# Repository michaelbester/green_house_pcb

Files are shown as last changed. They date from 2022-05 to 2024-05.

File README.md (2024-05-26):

This is the PCB design for the green house controller.  I used Kicad 6 to design the schematic and layout the board.

green_house_controller

pcb_pic

The uC pins connected to the fan #2, misc, and vent relays where incorrect.  
I jumpered these pins to unused pins that had output capability, but I can't get the outputs to go high.

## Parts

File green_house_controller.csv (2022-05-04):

Source: | /Volumes/MASTERs 17/green_house_controller/green_house_controller.kicad_sch
Date: | Friday, April 29, 2022 at 02:57:39 PM
Tool: | Eeschema (6.0.4-0)
Generator: | /Applications/KiCad/KiCad.app/Contents/SharedSupport/plugins/bom_csv_grouped_by_value_with_fp.py
Component Count: | 110
Ref | Qnty | Value | Cmp name | Footprint | Description | Vendor
C1, C10, | 2 | 0.1uF | C | Capacitor_SMD:C_0805_2012Metric | Unpolarized capacitor
C2, | 1 | 20uF | C | Capacitor_SMD:C_0805_2012Metric | Unpolarized capacitor
C3, | 1 | 1uF | C | Capacitor_SMD:C_0805_2012Metric | Unpolarized capacitor
C4, C5, C15, | 3 | 4.7uF | C | Capacitor_SMD:C_0805_2012Metric | Unpolarized capacitor
C6, | 1 | 0.01uF | C | Capacitor_SMD:C_0805_2012Metric | Unpolarized capacitor
C7, | 1 | 47pF | C | Capacitor_SMD:C_0805_2012Metric | Unpolarized capacitor
C8, | 1 | 1nF | C | Capacitor_SMD:C_0805_2012Metric | Unpolarized capacitor
C9, | 1 | 15nF | C | Capacitor_SMD:C_0805_2012Metric | Unpolarized capacitor
C11, C12, | 2 | 47uF | C | Capacitor_SMD:C_0805_2012Metric | Unpolarized capacitor
C13, | 1 | 2.2uF | C | Capacitor_SMD:C_0805_2012Metric | Unpolarized capacitor
C14, | 1 | 220pF | C | Capacitor_SMD:C_0805_2012Metric | Unpolarized capacitor
C17, | 1 | 2200uF | C_Polarized_US | Capacitor_THT:CP_Radial_D16.0mm_P7.50mm | Polarized capacitor, US symbol
D1, | 1 | SOL_1 | LED | LED_SMD:LED_0805_2012Metric | Light emitting diode
D2, | 1 | SOL_2 | LED | LED_SMD:LED_0805_2012Metric | Light emitting diode
D3, | 1 | SOL_3 | LED | LED_SMD:LED_0805_2012Metric | Light emitting diode
D4, D9, | 2 | B240 | B240 | Diode_SMD:D_SMB | 40V 2A Schottky Barrier Rectifier Diode, SMB
D5, | 1 | FAN | LED | LED_SMD:LED_0805_2012Metric | Light emitting diode
D6, | 1 | VENT | LED | LED_SMD:LED_0805_2012Metric | Light emitting diode
D7, | 1 | STATUS | LED | LED_SMD:LED_0805_2012Metric | Light emitting diode
D8, | 1 | MISC_1 | LED | LED_SMD:LED_0805_2012Metric | Light emitting diode
D10, | 1 | VENT_1 | LED | LED_SMD:LED_0805_2012Metric | Light emitting diode
D11, D12, D13, D14, D15, D16, | 6 | BAT54S | BAT54S | Package_TO_SOT_SMD:SOT-23 | schottky barrier diode
D17, | 1 | B140-E3 | B140-E3 | Diode_SMD:D_SMA | 40V 1A Schottky Barrier Rectifier Diode, SMA(DO-214AC)
H1, H2, H3, H4, | 4 | MountingHole | MountingHole | MountingHole:MountingHole_3.2mm_M3 | Mounting Hole without connection
J1, | 1 | TC2030-IDC | TC2030-IDC-TC2030-IDC | connector:TC2030-IDC
J2, | 1 | Screw_Terminal_01x10 | Screw_Terminal_01x10 | Connector_Phoenix_MC_HighVoltage:PhoenixContact_MCV_1,5_10-G-5.08_1x10_P5.08mm_Vertical | Generic screw terminal, single row, 01x10, script generated (kicad-library-utils/schlib/autogen/connector/)
J3, | 1 | USB_B_Mini | USB_B_Mini-Connector | Connector_USB:USB_Mini-B_Lumberg_2486_01_Horizontal
J4, | 1 | Screw_Terminal_01x06 | Screw_Terminal_01x06 | Connector_Phoenix_MC_HighVoltage:PhoenixContact_MCV_1,5_6-G-5.08_1x06_P5.08mm_Vertical | Generic screw terminal, single row, 01x06, script generated (kicad-library-utils/schlib/autogen/connector/)
J5, | 1 | Screw_Terminal_01x03 | Screw_Terminal_01x03 | Connector_Phoenix_MC_HighVoltage:PhoenixContact_MCV_1,5_3-G-5.08_1x03_P5.08mm_Vertical | Generic screw terminal, single row, 01x03, script generated (kicad-library-utils/schlib/autogen/connector/)
J6, | 1 | Barrel_Jack | Barrel_Jack | Connector_BarrelJack:BarrelJack_CUI_PJ-102AH_Horizontal | DC Barrel Jack
L1, L2, | 2 | 10uH | INDUCTOR | Inductor_SMD:L_Taiyo-Yuden_NR-50xx | Inductor symbol for simulation only
Q1, Q2, Q7, Q8, Q13, Q19, | 6 | 2N7002 | 2N7002 | Package_TO_SOT_SMD:SOT-23 | 0.115A Id, 60V Vds, N-Channel MOSFET, SOT-23
Q3, Q5, Q9, Q11, Q14, Q16, | 6 | DMP3068L | AO3401A | Package_TO_SOT_SMD:SOT-23 | -4.0A Id, -30V Vds, P-Channel MOSFET, SOT-23
Q4, Q6, Q10, Q12, Q15, Q17, | 6 | DMG3406L | DMG3406L | Package_TO_SOT_SMD:SOT-23 | 3.6A Id, 30V Vds, N-Channel MOSFET, SOT-23
R1, R12, R16, R17, R18, R19, | 6 | 10K | R_US | Resistor_SMD:R_0805_2012Metric | Resistor, US symbol
R2, R3, R4, R6, R7, R8, R9, R10, | 8 | 330 | R_US | Resistor_SMD:R_0805_2012Metric | Resistor, US symbol
R5, R24, R25, R26, R27, R28, R29, R30, R32, R33, R34, R35, R36, | 13 | 1K | R_US | Resistor_SMD:R_0805_2012Metric | Resistor, US symbol
R11, | 1 | 22K | R_US | Resistor_SMD:R_0805_2012Metric | Resistor, US symbol
R13, | 1 | 29.4K | R_US | Resistor_SMD:R_0805_2012Metric | Resistor, US symbol
R14, | 1 | 10.2K | R_US | Resistor_SMD:R_0805_2012Metric | Resistor, US symbol
R15, | 1 | 3.24K | R_US | Resistor_SMD:R_0805_2012Metric | Resistor, US symbol
R20, R21, R22, R23, | 4 | 200 | R_US | Resistor_SMD:R_0805_2012Metric | Resistor, US symbol
R31, | 1 | 51K | R_US | Resistor_SMD:R_0805_2012Metric | Resistor, US symbol
R37, | 1 | 18.7K | R_US | Resistor_SMD:R_0805_2012Metric | Resistor, US symbol
R38, | 1 | 100 | R_US | Resistor_SMD:R_2512_6332Metric | Resistor, US symbol
SW1, | 1 | SW_Push | SW_Push | Button_Switch_SMD:SW_SPST_B3S-1000 | Push button switch, generic, two pins
U1, | 1 | ESP32-WROVER | ESP32-WROVER-esp32-wrover | esp32-wrover:ESP32-WROVER
U2, | 1 | TPS54231 | TPS54233 | Package_SO:SOIC-8_3.9x4.9mm_P1.27mm | 2A, Step Down DC-DC Converter with Eco-mode, 3.5-28V Input Voltage, SO-8
U3, U4, U5, U6, | 4 | TLP3825TP1_F | TLP3825TP1_F | Package_DIP:DIP-8_W7.62mm
U7, | 1 | LM2733XMF | LM2733XMF | Package_TO_SOT_SMD:SOT-23-5 | LM27313, 1A, 40Vout Boost Voltage Regulator, 1.6MHz Frequency, SOT-23-5
U8, | 1 | DHT11 | DHT11 | Sensor:Aosong_DHT11_5.5x12.0_P2.54mm | Temperature and humidity module

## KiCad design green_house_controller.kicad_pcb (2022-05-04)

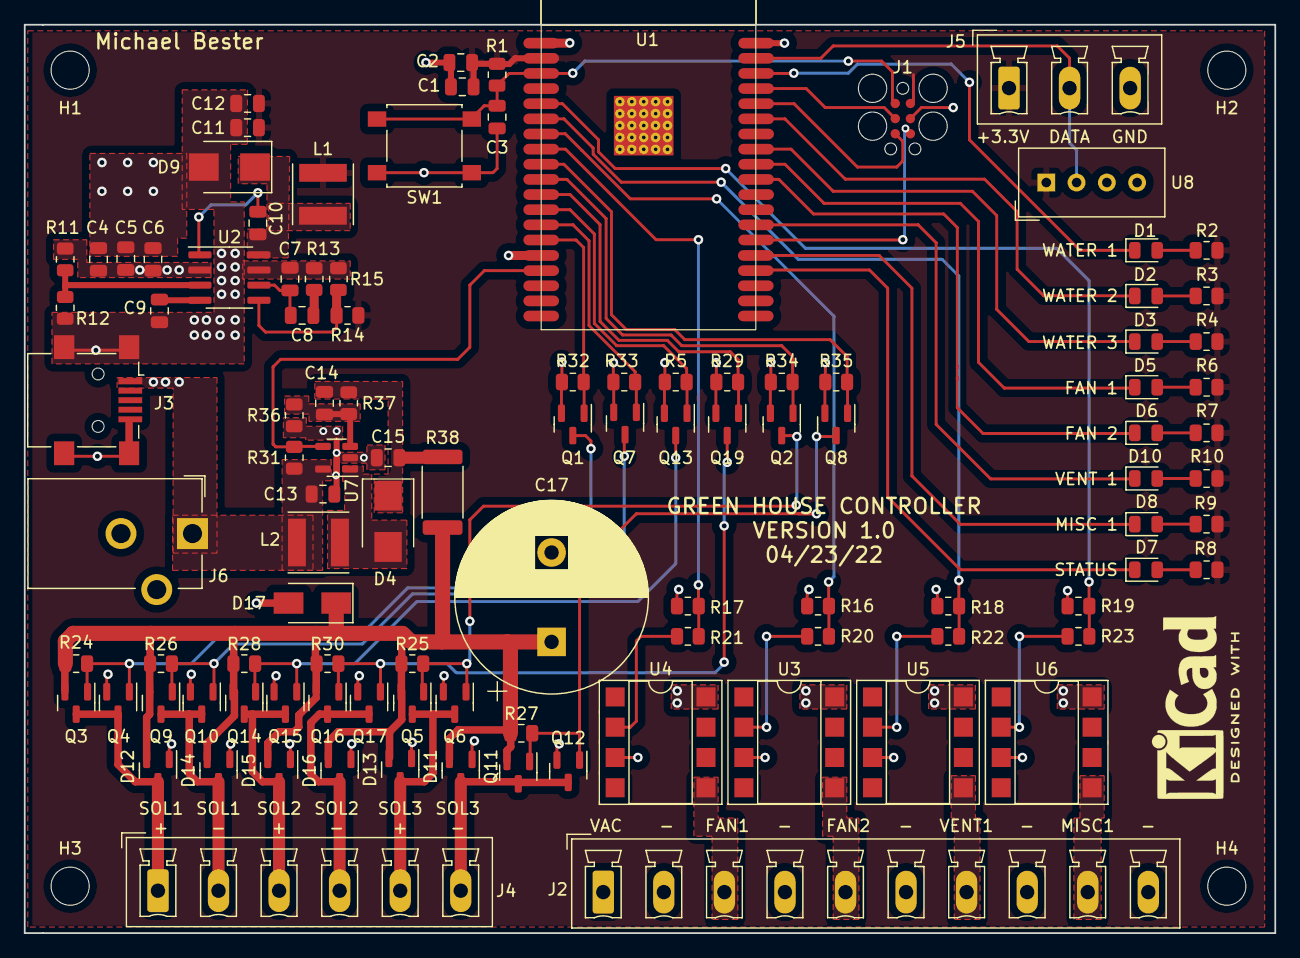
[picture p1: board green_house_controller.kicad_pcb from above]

Board: 2 copper layers, 104.9 x 76.2 mm, 110 parts (0 on the bottom side), 68 nets.

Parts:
C1, C10: 0.1uF; C_0805_2012Metric
C2: 10uF; C_0805_2012Metric
C3: 1uF; C_0805_2012Metric
C4, C5, C15: 4.7uF; C_0805_2012Metric
C6: 0.01uF; C_0805_2012Metric
C7: 47pF; C_0805_2012Metric
C8: 1nF; C_0805_2012Metric
C9: 15nF; C_0805_2012Metric
C11, C12: 47uF; C_0805_2012Metric
C13: 2.2uF; C_0805_2012Metric
C14: 220pF; C_0805_2012Metric
C17: 2200uF; CP_Radial_D16.0mm_P7.50mm
D1: SOL_1; LED_0805_2012Metric
D2: SOL_2; LED_0805_2012Metric
D3: SOL_3; LED_0805_2012Metric
D4, D9: B240; D_SMB
D5: FAN; LED_0805_2012Metric
D6: VENT; LED_0805_2012Metric
D7: STATUS; LED_0805_2012Metric
D8: MISC_1; LED_0805_2012Metric
D10: VENT_1; LED_0805_2012Metric
D11, D12, D13, D14, D15, D16: BAT54S; SOT-23
D17: B140-E3; D_SMA
H1, H2, H3, H4: MountingHole; MountingHole_3.2mm_M3
J1: TC2030-IDC
J2: Screw_Terminal_01x10; PhoenixContact_MCV_1,5_10-G-5.08_1x10_P5.08mm_Vertical
J3: USB_B_Mini; USB_Mini-B_Lumberg_2486_01_Horizontal
J4: Screw_Terminal_01x06; PhoenixContact_MCV_1,5_6-G-5.08_1x06_P5.08mm_Vertical
J5: Screw_Terminal_01x03; PhoenixContact_MCV_1,5_3-G-5.08_1x03_P5.08mm_Vertical
J6: Barrel_Jack; BarrelJack_CUI_PJ-102AH_Horizontal
L1, L2: 10uH; L_Taiyo-Yuden_NR-50xx
Q1, Q2, Q7, Q8, Q13, Q19: 2N7002; SOT-23
Q3, Q5, Q9, Q11, Q14, Q16: DMP3068L; SOT-23
Q4, Q6, Q10, Q12, Q15, Q17: DMG3406L; SOT-23
R1, R12, R16, R17, R18, R19: 10K; R_0805_2012Metric
R2, R3, R4, R6, R7, R8, R9, R10: 330; R_0805_2012Metric
R5, R24, R25, R26, R27, R28, R29, R30, R32, R33, R34, R35, R36: 1K; R_0805_2012Metric
R11: 22K; R_0805_2012Metric
R13: 29.4K; R_0805_2012Metric
R14: 10.2K; R_0805_2012Metric
R15: 3.24K; R_0805_2012Metric
R20, R21, R22, R23: 200; R_0805_2012Metric
R31: 51K; R_0805_2012Metric
R37: 18.7K; R_0805_2012Metric
R38: 100; R_2512_6332Metric
SW1: SW_Push; SW_SPST_B3S-1000
U1: ESP32-WROVER
U2: TPS54231; SOIC-8_3.9x4.9mm_P1.27mm
U3, U4, U5, U6: TLP3825TP1_F; DIP-8_W7.62mm_SMDSocket_SmallPads
U7: LM2733XMF; SOT-23-5
U8: DHT11; Aosong_DHT11_5.5x12.0_P2.54mm

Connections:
+3V3: C1.1, C2.1, C11.1, C12.1, J1.2 (SWDIO), J5.1, L1.2, R1.1, R2.1, R3.1, R4.1, R6.1, R7.1, R8.1, R9.1, R10.1, R14.1, U1.2 (3V3), U8.1 (VCC)
+24V: C14.2, C15.1, D4.1 (K), R37.2, R38.1
+VDC: C17.1, D11.2, D12.2, D13.2, D14.2, D15.2, D16.2, D17.1 (K), Q3.2 (S), Q5.2 (S), Q9.2 (S), Q11.2 (S), Q14.2 (S), Q16.2 (S), R24.1, R25.1, R26.1, R27.1, R28.1, R30.1, R38.2
/microcontroller/BOOT_MODE: J1.6 (SWO), U1.25 (IO0)
/microcontroller/DHT11_DATA: J5.2, U1.37 (IO23), U8.2 (IO)
/microcontroller/EN_24V: R31.2, U1.16 (IO13), U7.4 (EN)
/microcontroller/ESP32_RX: J1.5 (GND), U1.34 (RXD0)
/microcontroller/ESP32_TX: J1.3 (NRESET), U1.35 (TXD0)
/microcontroller/FAN_1_CTRL: R17.1, R21.2, U1.8 (IO32_XTAL_32K_P)
/microcontroller/FAN_2_CTRL: R16.1, R20.2, U1.7 (IO35)
/microcontroller/LED_FAN_1: D5.1 (K), U1.30 (IO18)
/microcontroller/LED_FAN_2: D6.1 (K), U1.29 (IO5)
/microcontroller/LED_MISC_1: D8.1 (K), U1.24 (IO2)
/microcontroller/LED_SOL_1: D1.1 (K), U1.36 (IO22)
/microcontroller/LED_SOL_2: D2.1 (K), U1.33 (IO21)
/microcontroller/LED_SOL_3: D3.1 (K), U1.31 (IO19)
/microcontroller/LED_STATUS: D7.1 (K), U1.23 (IO15)
/microcontroller/LED_VENT_1: D10.1 (K), U1.26 (IO4)
/microcontroller/MISC_1_CTRL: R19.1, R23.2, U1.5 (SENSOR_VN_IO39)
/microcontroller/RESET: C3.1, J1.1 (VCC), R1.2, SW1.2, U1.3 (EN)
/microcontroller/SOL_1_CLOSE_CTRL: Q1.1 (G), R32.1, U1.14 (IO12)
/microcontroller/SOL_1_OPEN_CTRL: Q7.1 (G), R33.1, U1.13 (IO14)
/microcontroller/SOL_2_CLOSE_CTRL: Q13.1 (G), R5.1, U1.12 (IO27)
/microcontroller/SOL_2_OPEN_CTRL: Q19.1 (G), R29.1, U1.11 (IO26)
/microcontroller/SOL_3_CLOSE_CTRL: Q2.1 (G), R34.1, U1.10 (IO25)
/microcontroller/SOL_3_OPEN_CTRL: Q8.1 (G), R35.1, U1.9 (IO33_XTAL_32K_N)
/microcontroller/VENT_1_CTRL: R18.1, R22.2, U1.6 (IO34)
/power supply/VIN: C4.1, C5.1, C6.1, C13.1, J3.1 (VBUS), J6.1, L2.1, R11.1, R31.1, U2.2 (VIN), U7.5 (VIN)
/relay control/110VAC: J2.1, U3.8 (DRAIN), U4.8 (DRAIN), U5.8 (DRAIN), U6.8 (DRAIN)
/relay control/FAN_1_PWR: J2.3, U4.5 (DRAIN)
/relay control/FAN_2_PWR: J2.5, U3.5 (DRAIN)
/relay control/MISC_1_PWR: J2.9, U6.5 (DRAIN)
/relay control/VENT_1_PWR: J2.7, U5.5 (DRAIN)
/solenoid control/SOL_1_PWR+: D12.3, J4.1, Q3.3 (D), Q4.3 (D)
/solenoid control/SOL_1_PWR-: D14.3, J4.2, Q9.3 (D), Q10.3 (D)
/solenoid control/SOL_2_PWR+: D15.3, J4.3, Q14.3 (D), Q15.3 (D)
/solenoid control/SOL_2_PWR-: D16.3, J4.4, Q16.3 (D), Q17.3 (D)
/solenoid control/SOL_3_PWR+: D11.3, J4.5, Q5.3 (D), Q6.3 (D)
/solenoid control/SOL_3_PWR-: D13.3, J4.6, Q11.3 (D), Q12.3 (D)
Earth: J2.2, J2.4, J2.6, J2.8, J2.10
GND: C1.2, C2.2, C3.2, C4.2, C5.2, C6.2, C7.2, C9.2, C11.2, C12.2, C13.2, C15.2, C17.2, D9.2 (A), D11.1, D12.1, D13.1, D14.1, D15.1, D16.1, D17.2 (A), J1.4 (SWCLK), J3.5 (GND), J3.6 (Shield), J5.3, J6.2, Q1.2 (S), Q2.2 (S), Q4.2 (S), Q6.2 (S), Q7.2 (S), Q8.2 (S), Q10.2 (S), Q12.2 (S), Q13.2 (S), Q15.2 (S), Q17.2 (S), Q19.2 (S), R5.2, R12.2, R13.2, R15.2, R16.2, R17.2, R18.2, R19.2, R29.2, R32.2, R33.2, R34.2, R35.2, R36.1, SW1.1, U1.1 (GND), U1.15 (GND), U1.38 (GND), U1.39 (GND), U2.7 (GND), U3.3 (CATHODE), U4.3 (CATHODE), U5.3 (CATHODE), U6.3 (CATHODE), U7.2 (GND), U8.4 (GND)
unnamed: C7.1, C8.1, U2.6 (COMP)
unnamed: C8.2, R13.1
unnamed: C9.1, U2.4 (SS)
unnamed: C10.1, U2.1 (BOOT)
unnamed: C10.2, D9.1 (K), L1.1, U2.8 (PH)
unnamed: C14.1, R36.2, R37.1, U7.3 (FB)
unnamed: D1.2 (A), R2.2
unnamed: D2.2 (A), R3.2
unnamed: D3.2 (A), R4.2
unnamed: D4.2 (A), L2.2, U7.1 (SW)
unnamed: D5.2 (A), R6.2
unnamed: D6.2 (A), R7.2
unnamed: D7.2 (A), R8.2
unnamed: D8.2 (A), R9.2
unnamed: D10.2 (A), R10.2
unnamed: Q1.3 (D), Q3.1 (G), Q4.1 (G), R24.2
unnamed: Q2.3 (D), Q5.1 (G), Q6.1 (G), R25.2
unnamed: Q7.3 (D), Q9.1 (G), Q10.1 (G), R26.2
unnamed: Q8.3 (D), Q11.1 (G), Q12.1 (G), R27.2
unnamed: Q13.3 (D), Q14.1 (G), Q15.1 (G), R28.2
unnamed: Q16.1 (G), Q17.1 (G), Q19.3 (D), R30.2
unnamed: R11.2, R12.1, U2.3 (EN)
unnamed: R14.2, R15.1, U2.5 (FB)
unnamed: R20.1, U3.2 (ANODE)
unnamed: R21.1, U4.2 (ANODE)
unnamed: R22.1, U5.2 (ANODE)
unnamed: R23.1, U6.2 (ANODE)

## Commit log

2022-04-25 Initial commit.
    [green_house_controller.kicad_pcb, green_house_controller.kicad_sch, green_house_controller.sch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]
2022-04-26 Added connector for temperature sensor. Started to route board.
    [green_house_controller.kicad_pcb, green_house_controller.kicad_sch, microcontroller.kicad_sch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]
2022-04-26 Added clamping diode for 24V net.
    [green_house_controller.kicad_pcb, green_house_controller.kicad_sch, microcontroller.kicad_sch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]
2022-04-26 Flipped top fets for solenoid controls so that the body diode was pointing the correction direction.
    [green_house_controller.kicad_pcb, solenoid_control.kicad_sch]
2022-04-27 Continued with layout.
    [green_house_controller.kicad_pcb, green_house_controller.kicad_sch, microcontroller.kicad_sch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]
2022-04-28 Finished layout for +24V regulator circuit.
    [green_house_controller.kicad_pcb]
2022-04-29 Finished initial layout. Zero DRC errors/warnings.
    [green_house_controller.kicad_pcb, green_house_controller.kicad_sch, microcontroller.kicad_sch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]
2022-04-29 Added DHT11 footprint. Updated feedback resistor values for regulator circuit. Created gerber and drill files for version 1.
    [green_house_controller.kicad_pcb, green_house_controller.kicad_sch, power_supply.kicad_sch]
2022-04-29 Fixed 3.3V net disconnection issue.
    [green_house_controller.kicad_pcb]
2022-05-04 Replaced relays with smd versions.
    [green_house_controller-B_Cu.gbr, green_house_controller-B_Mask.gbr, green_house_controller-B_Paste.gbr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]
2025-01-25 Initial part placement on PCB
